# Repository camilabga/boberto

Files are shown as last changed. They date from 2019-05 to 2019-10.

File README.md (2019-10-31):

# Boberto: 2019 IEEE Open Competition Robot

Boberto was a robot developed by six students of LAR-UFRN (https://github.com/lar-ect). The competition consisted in proposing, developing and manufacturing a robot able to solve a portuary challenge.

2019 IEEE Open was a part of LARC (Latin American Robotics Competition) and happened in Rio Grande, RS, Brazil. The robot described here accomplished the second place, but is also currently the two-time Brazilian champion in the category.

The main goal was deposit as much containers as possible in a enviroment with a simulation of two ships (one blue and other green) and one train (red). Each container had a different pontuation. The team with the greatest score would win the challenge.

Boberto was able to:
1. Identify and advance to a container zone;
2. Choose a container to pick and check its color;
3. If it consisted in a Blue/Green container, grab it and go to the ship zone;
4. If it consisted in a Red container, ignore it and keep moving to the next pile;
5. Come back and do it all over again;

The official document of the competition can be found [here](http://www.cbrobotica.org/wp-content/uploads/OPEN2018_2019_en.pdf).

The students that composed the team of LAR-UFRN were:
* Álvaro Portela (https://github.com/alvaropfn)
* Camila Barbosa (https://github.com/camilabga)
* Gabriel Vantuil (https://github.com/GabrielVantuil)
* Luiz Felipe Santana (https://github.com/LuizFelipeLemon)
* Richardson Santiago (https://github.com/vanluwin)
* Wendell Alves (https://github.com/wendellalves)

## Using [PlatformIO Cli](http://docs.platformio.org/en/latest/)

* Installing

```console
user@computer:~$ sudo python -c "$(curl -fsSL https://raw.githubusercontent.com/platformio/platformio/develop/scripts/get-platformio.py)"
```

* Uploading the code

```console
user@computer:~/IEEE-2019 $ pio run -t upload --upload-port=/dev/ttyUSB0
```

## Arduino Mega Schema

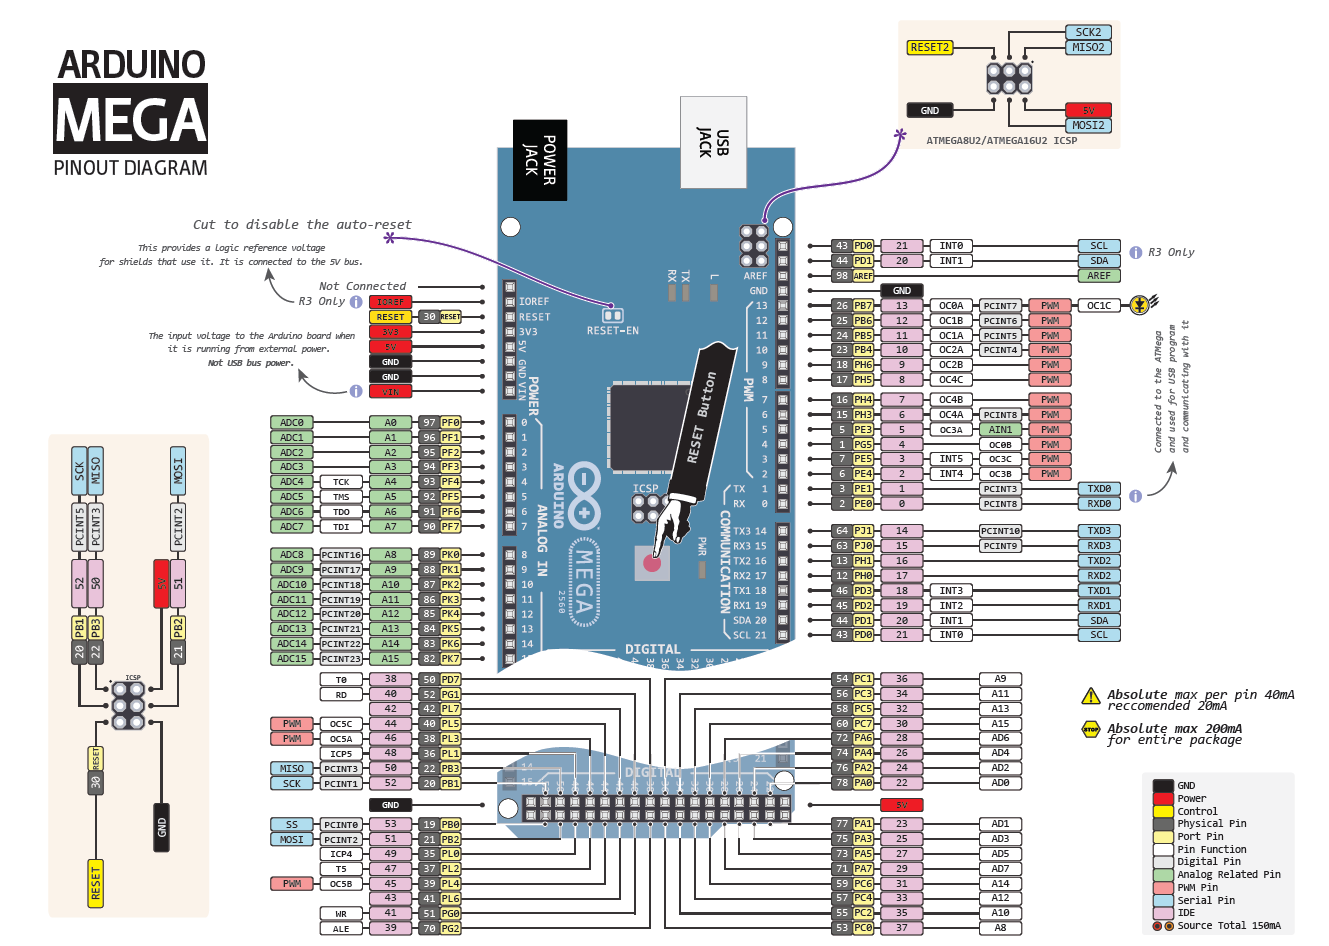
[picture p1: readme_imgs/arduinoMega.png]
arduinoMega


## Boberto Pinout

### Stepper motor

| Port | Pin |
|:---: |:---:|
| Dir | 52 |
| Step | 50 |
| Enable | 13 |

### H Bridge 1

| Port | Pin |
|:---: |:---:|
| Claw_DC 1 | 11 |
| Claw_DC 2 | 12 |
| Motor 2.1 | 9 |
| Motor 2.2 | 10 |

### H Bridge 2

| Port | Pin |
|:---: |:---:|
| Back Left 2  | 7 |
| Back Left 1  | 8 |
| Back Right 2 | 6 |
| Back Right 1 | 5 |

### H Bridge 3

| Port | Pin |
|:---:|:---:|
| Front Right 1 | 45 |
| Front Right 2 | 4 |
| Front Left 1  | 46 |
| Front Left 2  | 44 |

### Encoders

| Port | Pin |
|:---:|:---:|
| Back Left  | 3 |
| Back Right | 2 |
| Front Right| 18 |
| Front Left | 19 |

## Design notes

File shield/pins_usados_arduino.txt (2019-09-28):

Pin:

- Motor de passo
	- 52 Dir
	- 50 Step
	- 13 enable

- Ponte H 1
	- 11 input 1
	- 12 input 2
	- 9 input 3
	- 10 input 4

- Ponte H 2
	- 7 input 1
	- 8 input 2
	- 6 input 3
	- 5 input 4

- Ponte H 3
	- 45 input 1
	- 4 input 2
	- 46 input 3
	- 44 input 4

- Encoders (Interrupt)
	- 3 - motor 1
	- 2 - motor 2
	- 18 - motor 3
	- 19 - motor 4

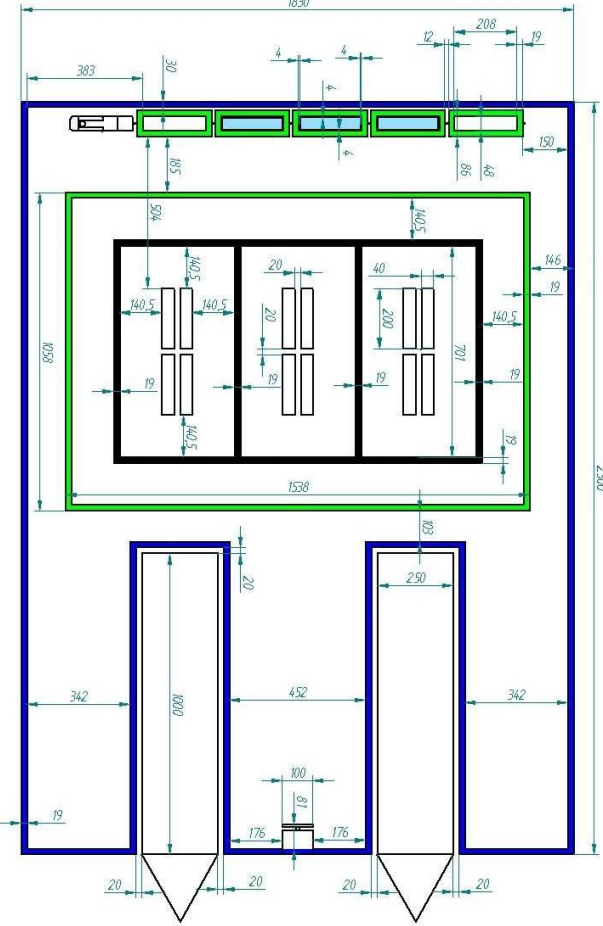
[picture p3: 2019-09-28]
readme_imgs/zones.png

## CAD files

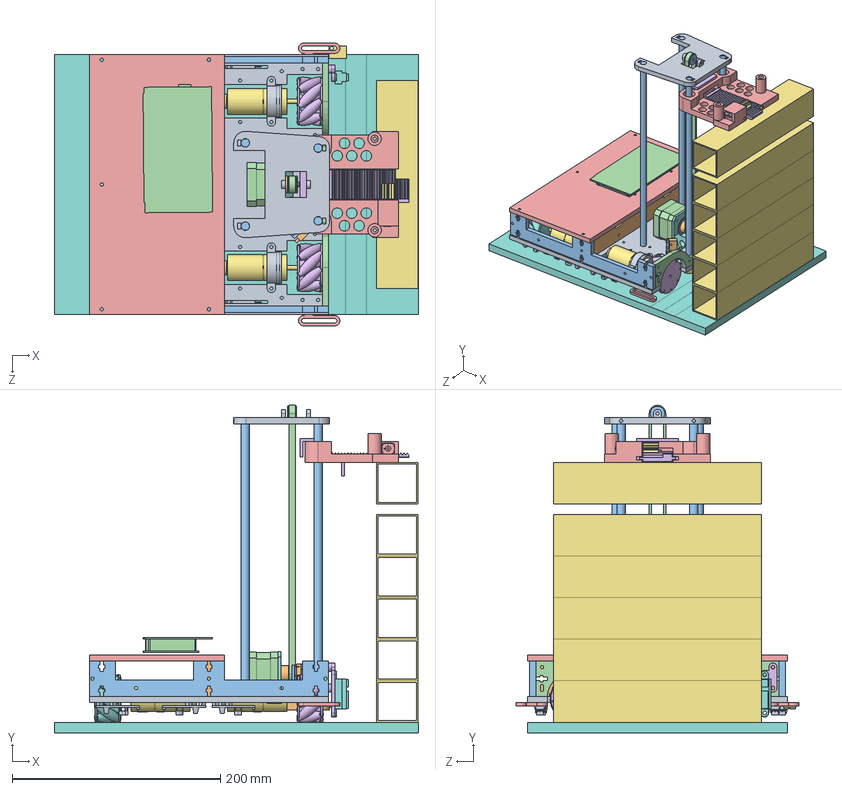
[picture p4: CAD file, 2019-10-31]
CAD/#Robo completo.SLDASM
350.0 x 315.0 x 272.0 mm
base
chassis meio
chassis reforco x 2
chassis direita x 2
segundo andar
Mecanum x 2
motor 12v com reducao e encoder x 4
EspelharMecanum x 2
suporte motor x 2
suporte barras base x 2
barra lisa 8mm x 4
nema17 (30mm altura)
suporte garra
cremalheira
engrenagem servo maior
suporte nema
suporte barras topo
polia gt2
polia com rolamento
correia
motor N20
suporte correia v2
container x 6
chao
sensor de linha x 6
endstop
suporte fim de curso
Ramps + arduino
suporte sensor de azul x 2
suporte sharp
sensor de azul
sharp

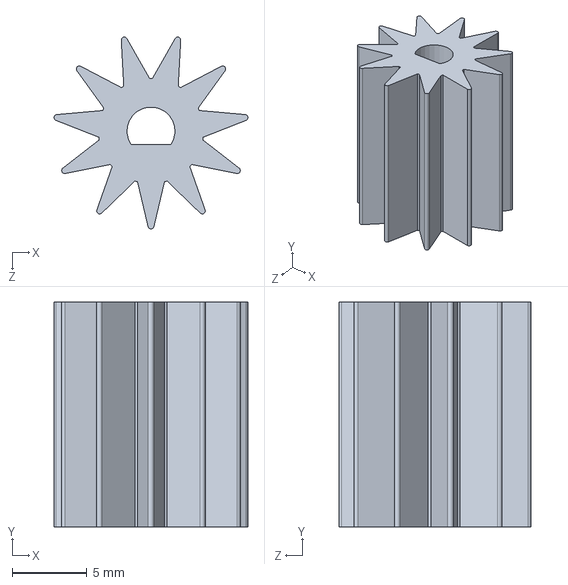
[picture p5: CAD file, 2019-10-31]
CAD/engrenagem servo maior.SLDPRT
12.9 x 15.0 x 12.8 mm

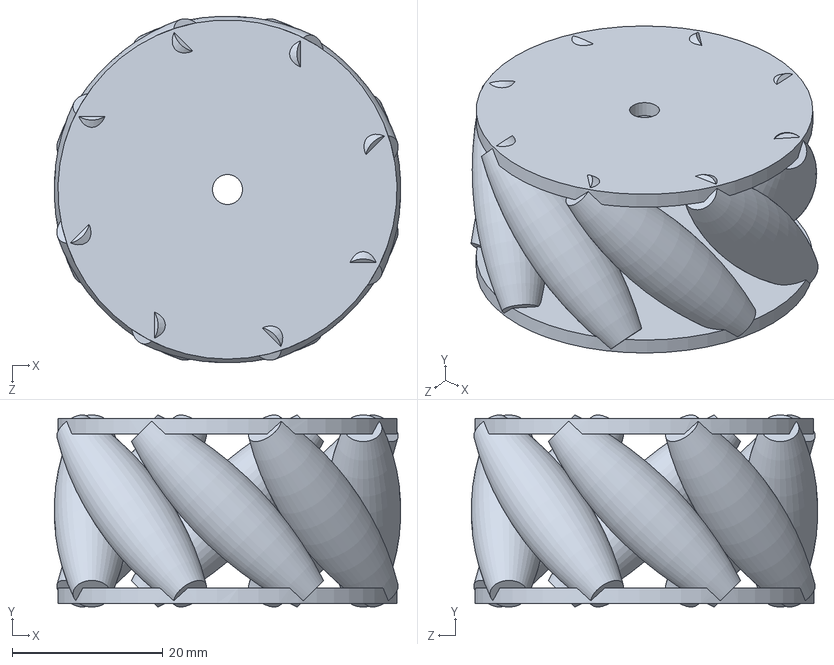
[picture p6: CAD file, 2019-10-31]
CAD/Mecanum.SLDPRT
45.9 x 25.5 x 45.9 mm

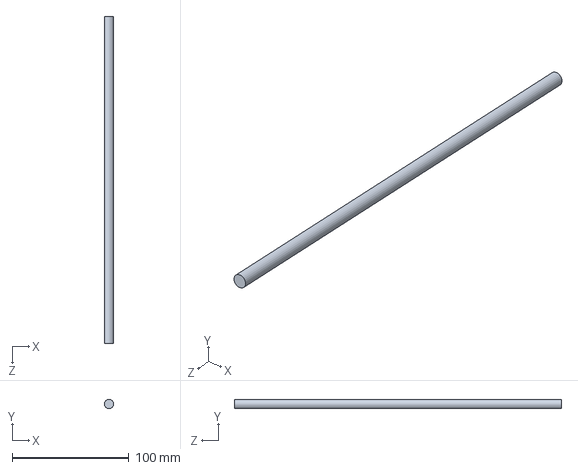
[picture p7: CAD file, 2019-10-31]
CAD/barra lisa 8mm.SLDPRT
8.00 x 8.00 x 280.0 mm

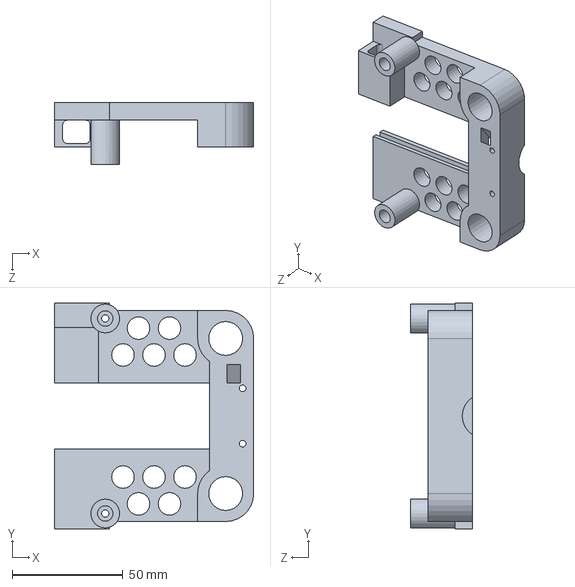
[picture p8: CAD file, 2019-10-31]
CAD/suporte garra.SLDPRT
90.0 x 102.0 x 28.0 mm

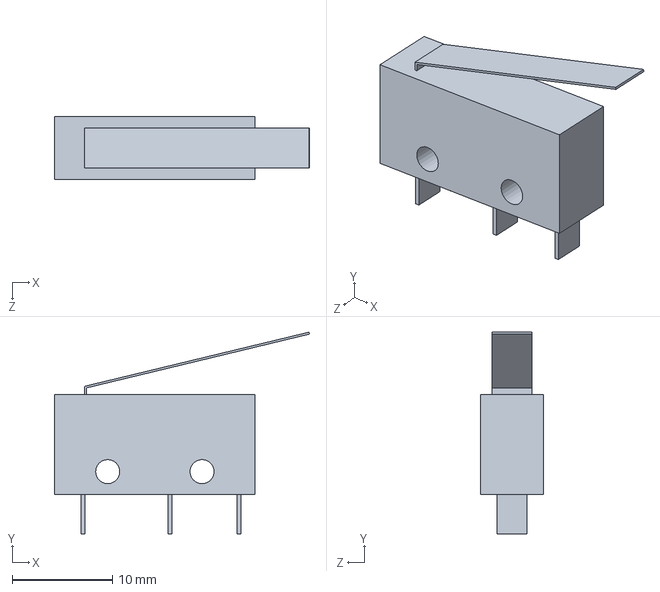
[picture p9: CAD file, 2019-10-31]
CAD/endstop.SLDPRT
25.4 x 20.1 x 6.30 mm

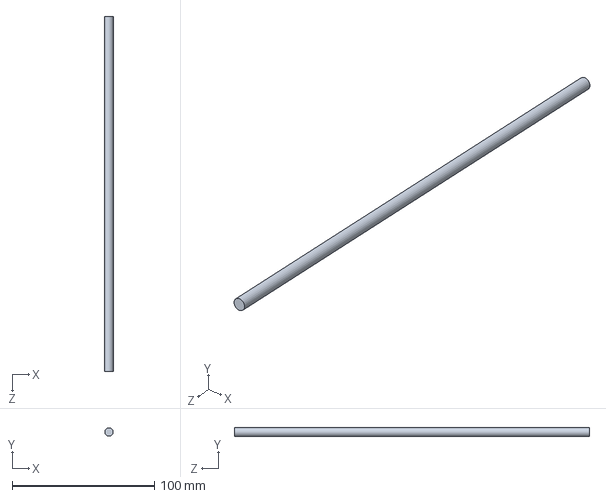
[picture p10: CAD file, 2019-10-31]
CAD/barra lisa 6mm.SLDPRT
6.00 x 6.00 x 250.0 mm

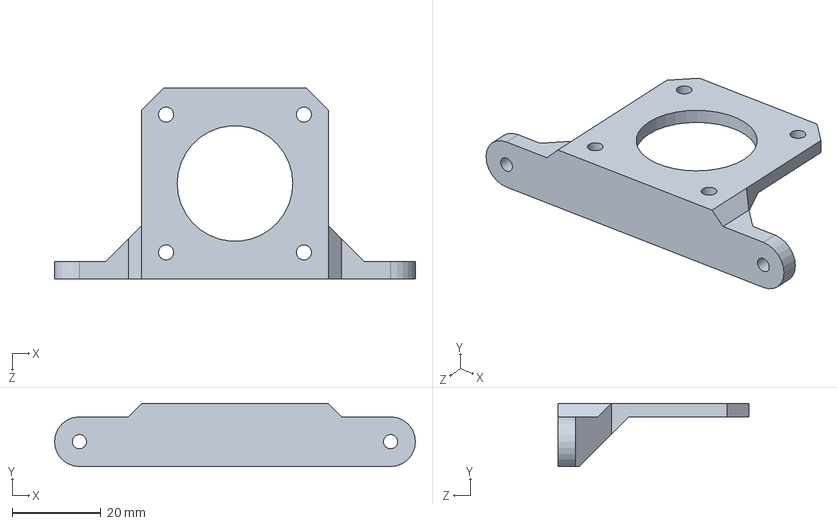
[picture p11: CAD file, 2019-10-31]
CAD/suporte nema.SLDPRT
81.2 x 14.2 x 43.0 mm

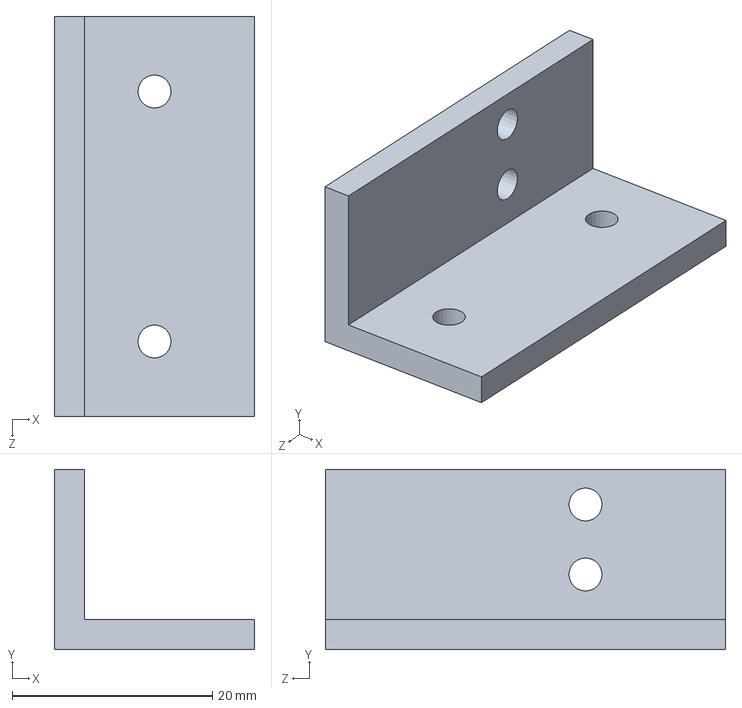
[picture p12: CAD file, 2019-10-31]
CAD/suporte correia v2.SLDPRT
20.0 x 18.0 x 40.0 mm

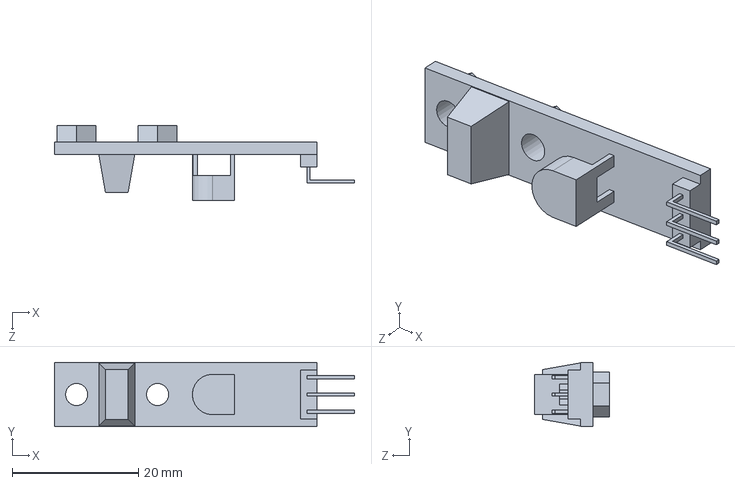
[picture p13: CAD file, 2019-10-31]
CAD/sensor de linha.SLDPRT
47.4 x 10.2 x 11.9 mm

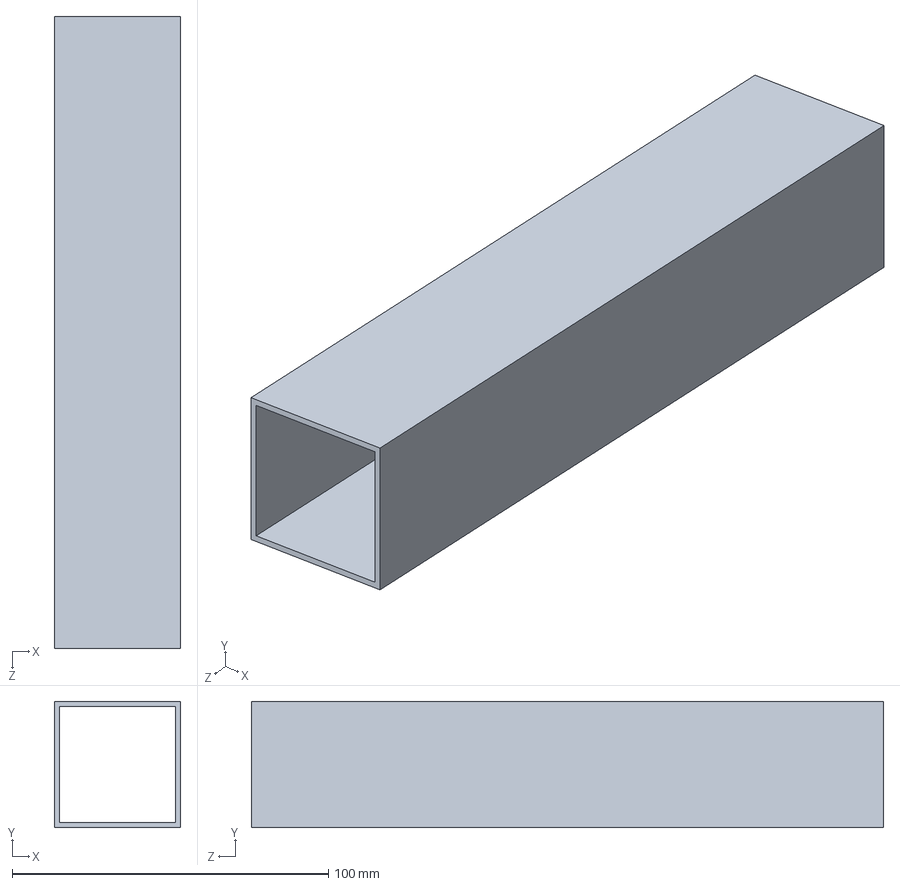
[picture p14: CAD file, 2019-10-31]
CAD/container.SLDPRT
40.0 x 40.0 x 200.0 mm

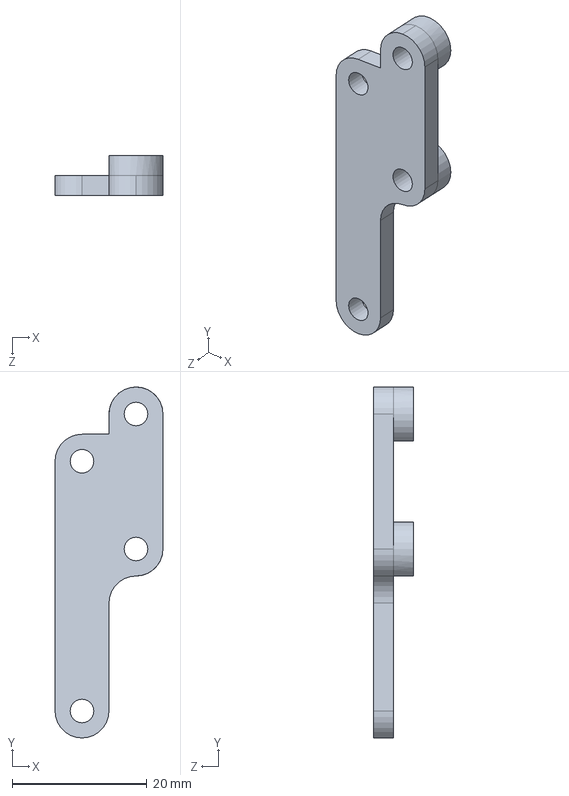
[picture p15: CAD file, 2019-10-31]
CAD/suporte sharp.SLDPRT
16.0 x 52.0 x 6.00 mm

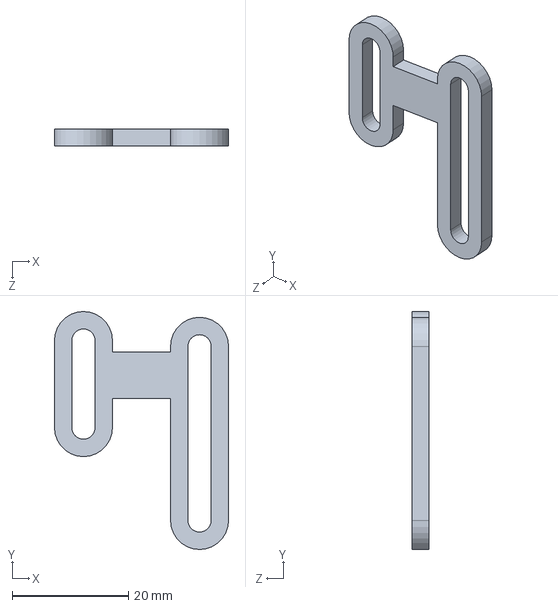
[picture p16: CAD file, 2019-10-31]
CAD/suporte sensor de azul.SLDPRT
30.0 x 41.0 x 3.00 mm

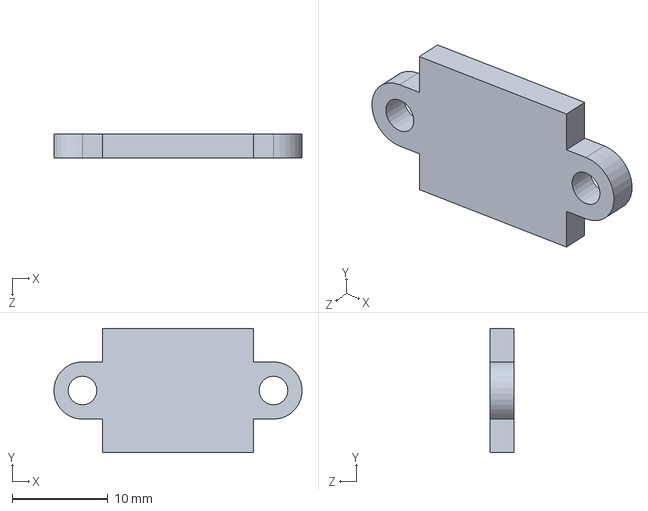
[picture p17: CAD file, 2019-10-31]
CAD/vl53l0x.SLDPRT
26.0 x 13.0 x 2.50 mm

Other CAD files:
CAD/2d (laser)/todas as peças.DWG
CAD/EspelharMecanum.SLDPRT
CAD/sharp.SLDPRT
CAD/suporte barras base.SLDPRT
CAD/2d (laser)/base.SLDDRW
CAD/2d (laser)/chassis 2x reforco + meio.SLDDRW
CAD/2d (laser)/chassis direita.SLDDRW
CAD/2d (laser)/todas as peças.SLDDRW
CAD/PCB + arduino.SLDPRT
CAD/Printable parts/cremalheira.STL
CAD/Printable parts/engrenagem servo maior.STL
CAD/Printable parts/suporte barras base.STL
CAD/Printable parts/suporte barras topo.STL
CAD/Printable parts/suporte correia v2.STL
CAD/Printable parts/suporte fim de curso.STL
CAD/Printable parts/suporte garra.STL
CAD/Printable parts/suporte motor.STL
CAD/Printable parts/suporte nema.STL
CAD/Printable parts/suporte sensor de azul.STL
CAD/Servo 9g.SLDPRT
CAD/apoio container.SLDPRT
CAD/base.SLDPRT
CAD/chao.SLDPRT
CAD/chassis direita.SLDPRT
CAD/chassis meio.SLDPRT
CAD/chassis reforco.SLDPRT
CAD/chassis.SLDPRT
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

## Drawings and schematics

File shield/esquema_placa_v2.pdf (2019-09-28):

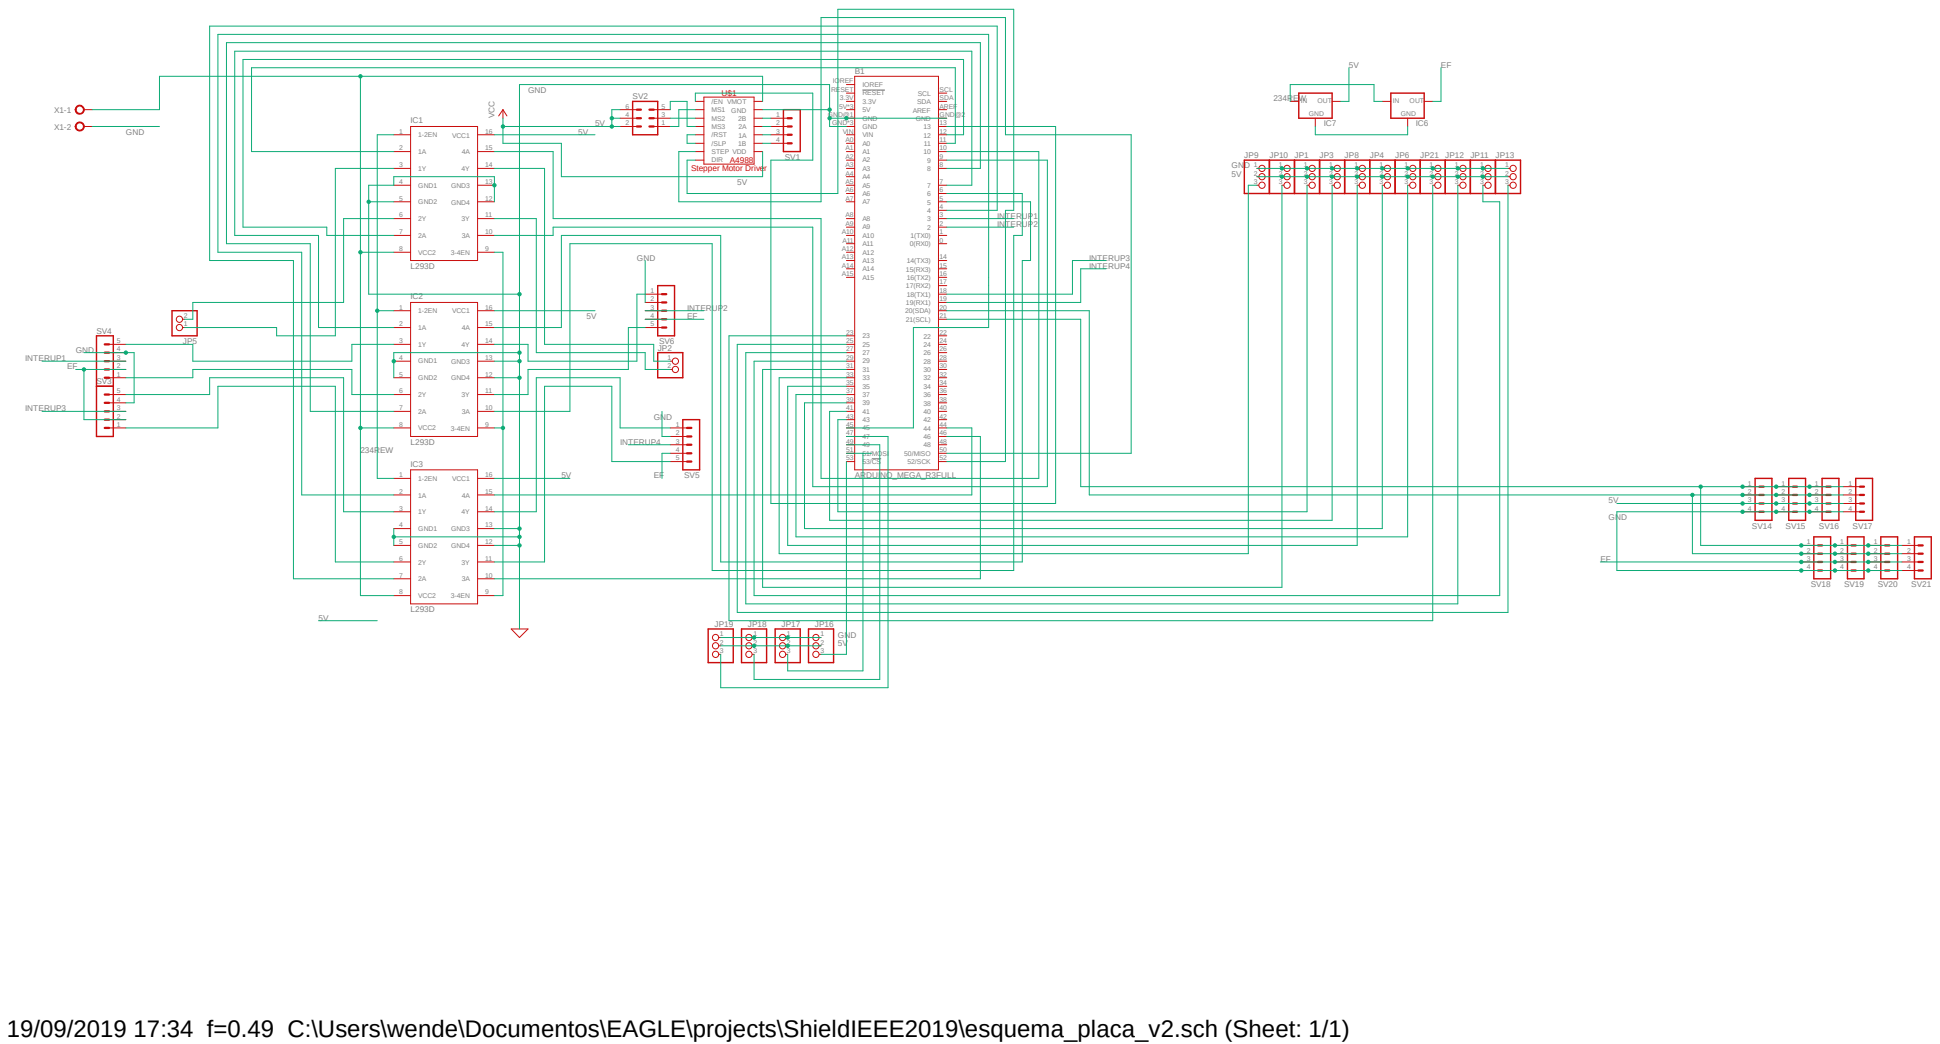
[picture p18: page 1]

GND1 4 GND4 3Y 3A | | | | 5V

GND2 5 | 12

2A 7 VCC2 8 | 10

19/09/2019 17:34 f=0.49 C:\Users\wende\Documentos\EAGLE\projects\ShieldIEEE2019\esquema_placa_v2.sch (Sheet: 1/1)

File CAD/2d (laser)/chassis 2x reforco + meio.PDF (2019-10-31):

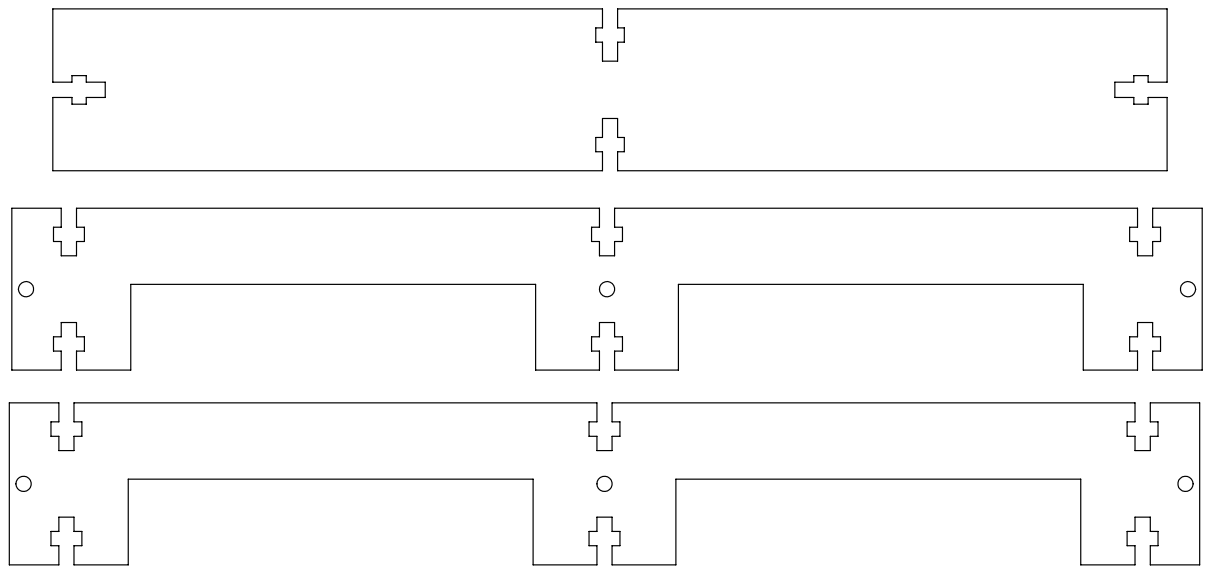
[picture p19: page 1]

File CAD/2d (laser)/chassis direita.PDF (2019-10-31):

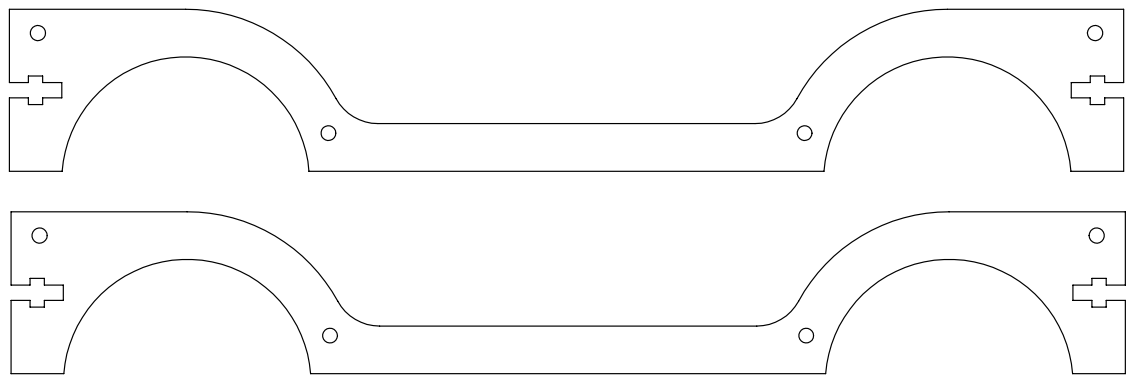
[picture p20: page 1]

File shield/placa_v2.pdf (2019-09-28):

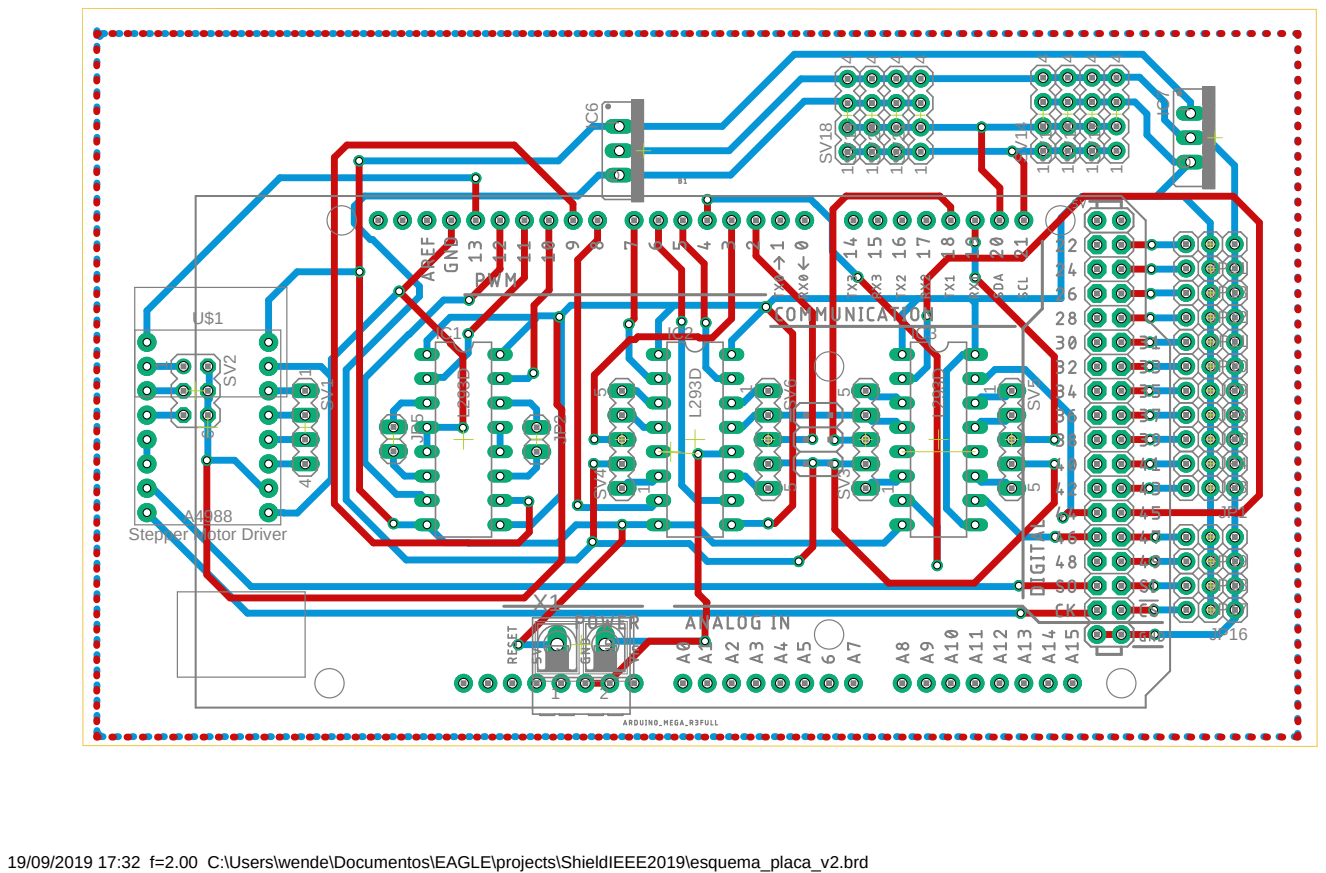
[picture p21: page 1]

19/09/2019 17:32 f=2.00 C:\Users\wende\Documentos\EAGLE\projects\ShieldIEEE2019\esquema_placa_v2.brd

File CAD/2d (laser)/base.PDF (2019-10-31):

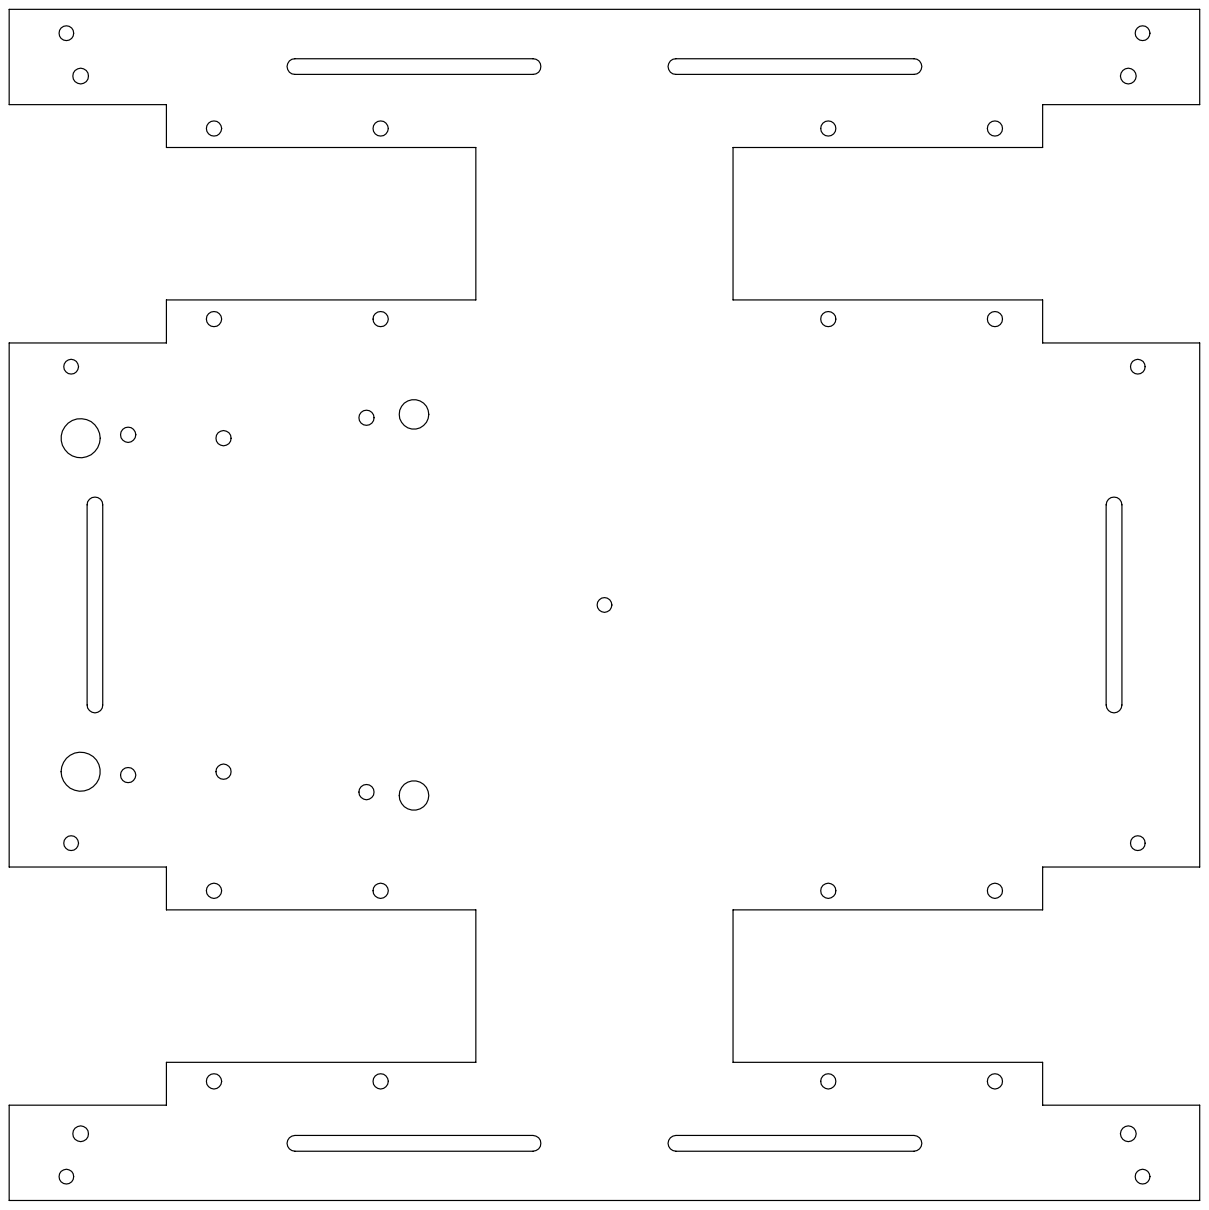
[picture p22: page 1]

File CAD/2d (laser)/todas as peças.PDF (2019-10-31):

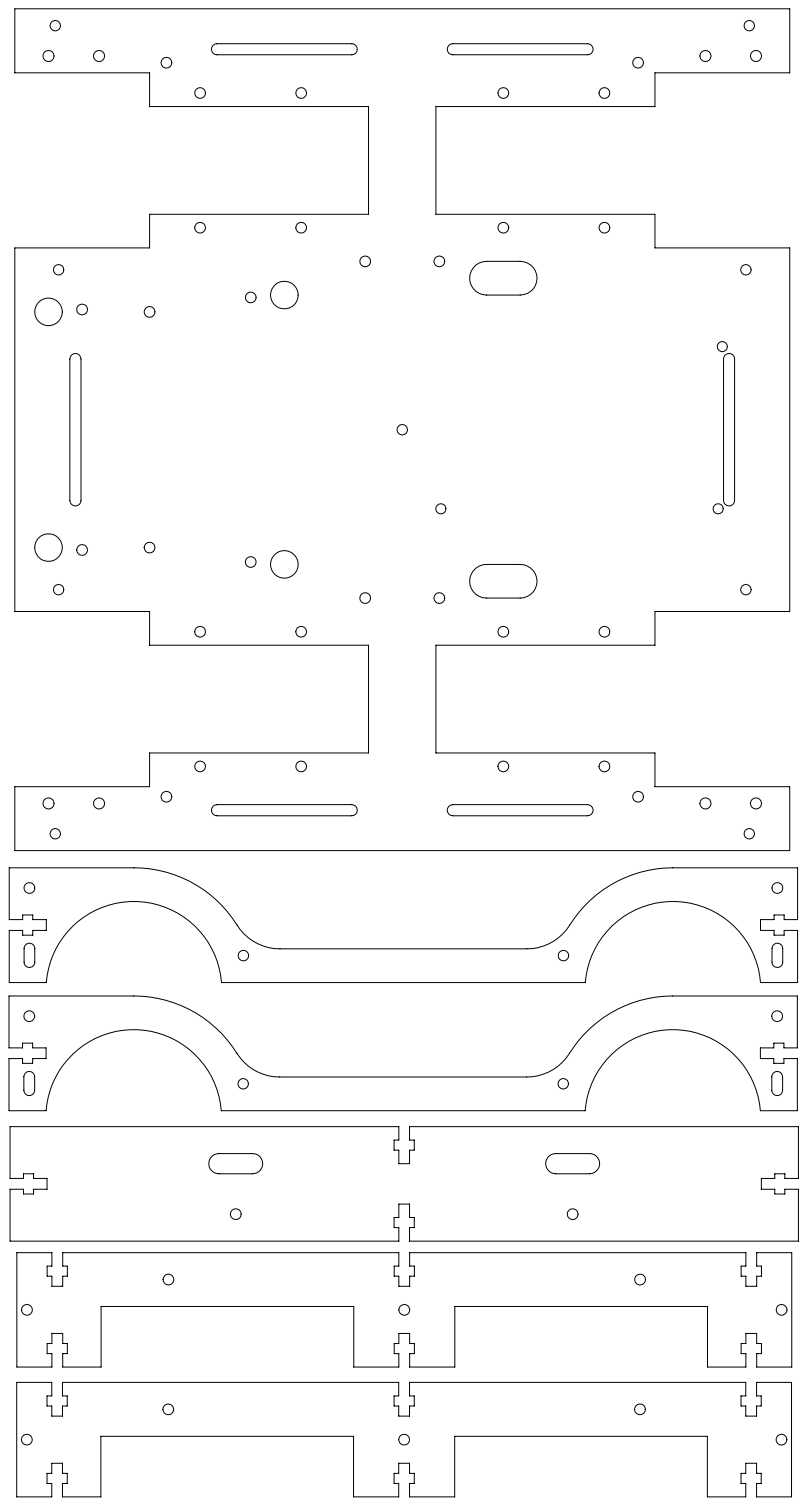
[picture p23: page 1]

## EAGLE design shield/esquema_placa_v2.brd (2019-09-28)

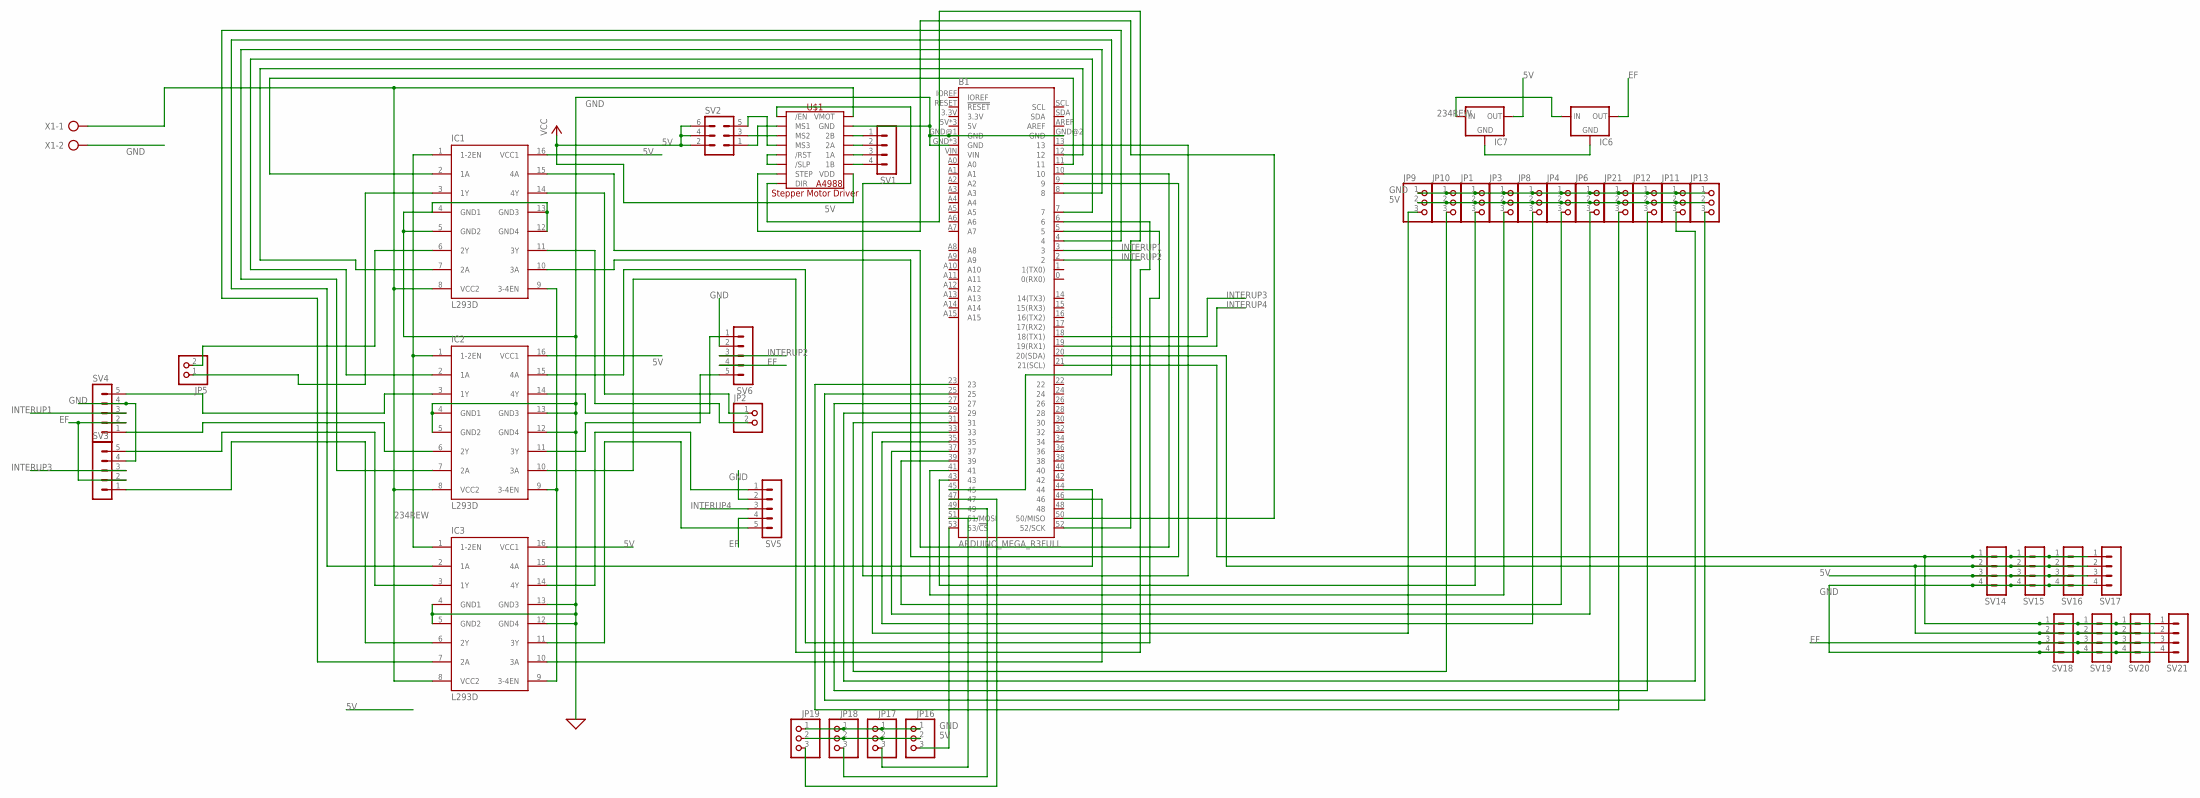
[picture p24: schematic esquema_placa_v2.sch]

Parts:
B1: ARDUINO_MEGA_R3FULL; ARDUINO_MEGA_NO_SILK
IC1, IC2, IC3: L293D; DIL16
IC6, IC7: 78XXS
JP1, JP3, JP4, JP6, JP8, JP9, JP10, JP11, JP12, JP13, JP16, JP17, JP18, JP19, JP21: PINHD-1X3; 1X03
JP2, JP5: PINHD-1X2; 1X02
SV1, SV14, SV15, SV16, SV17, SV18, SV19, SV20, SV21: MA04-1
SV2: MA03-2
SV3, SV4, SV5, SV6: MA05-1
U$1: A4988_STEP
X1: AK500/2-H

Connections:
5V: IC1.1 (1-2EN), IC1.9 (3-4EN), IC1.16 (VCC1), IC2.1 (1-2EN), IC2.9 (3-4EN), IC2.16 (VCC1), IC3.1 (1-2EN), IC3.9 (3-4EN), IC3.16 (VCC1), IC7.OUT, JP1.2, JP3.2, JP4.2, JP6.2, JP8.2, JP9.2, JP10.2, JP11.2, JP12.2, JP13.2, JP16.2, JP17.2, JP18.2, JP19.2, JP21.2, SV2.2, SV2.4, SV2.6, SV14.3, SV15.3, SV16.3, SV17.3, U$1.VDD
234REW: IC1.8 (VCC2), IC2.8 (VCC2), IC3.8 (VCC2), IC6.IN, IC7.IN, U$1.VMOT, X1.1
EF: IC6.OUT, SV3.2, SV4.2, SV5.4, SV6.4, SV18.3, SV19.3, SV20.3, SV21.3
GND: B1.GND, B1.GND@1 (GND), B1.GND@2 (GND), B1.GND@3 (GND), B1.GND@4 (GND), IC1.4 (GND1), IC1.5 (GND2), IC1.12 (GND4), IC1.13 (GND3), IC2.4 (GND1), IC2.5 (GND2), IC2.12 (GND4), IC2.13 (GND3), IC3.4 (GND1), IC3.5 (GND2), IC3.12 (GND4), IC3.13 (GND3), IC6.GND, IC7.GND, JP1.1, JP3.1, JP4.1, JP6.1, JP8.1, JP9.1, JP10.1, JP11.1, JP12.1, JP13.1, JP16.1, JP17.1, JP18.1, JP19.1, JP21.1, SV3.4, SV4.4, SV5.2, SV6.2, SV14.4, SV15.4, SV16.4, SV17.4, SV18.4, SV19.4, SV20.4, SV21.4, U$1.GND, U$1.GND2 (GND), X1.2
INTERUP1: B1.3, SV4.3
INTERUP2: B1.2, SV6.3
INTERUP3: B1.18 (18(TX1)), SV3.3
INTERUP4: B1.19 (19(RX1)), SV5.3
unnamed: B1.53 (53/!CS), JP16.3
unnamed: IC1.3 (1Y), JP5.1
unnamed: IC1.6 (2Y), JP5.2
unnamed: IC2.3 (1Y), SV4.5
unnamed: B1.45, IC3.2 (1A)
unnamed: IC2.6 (2Y), SV4.1
unnamed: IC3.3 (1Y), SV3.5
unnamed: IC3.6 (2Y), SV3.1
unnamed: IC2.14 (4Y), SV6.1
unnamed: IC2.11 (3Y), SV6.5
unnamed: IC3.14 (4Y), SV5.1
unnamed: IC3.11 (3Y), SV5.5
unnamed: IC1.11 (3Y), JP2.2
unnamed: IC1.14 (4Y), JP2.1
unnamed: B1.12, IC1.7 (2A)
unnamed: B1.11, IC1.2 (1A)
unnamed: B1.7, IC2.2 (1A)
unnamed: B1.8, IC2.7 (2A)
unnamed: B1.43, JP1.3
unnamed: B1.4, IC3.7 (2A)
unnamed: B1.10, IC1.15 (4A)
unnamed: B1.9, IC1.10 (3A)
unnamed: B1.5, IC2.15 (4A)
unnamed: B1.6, IC2.10 (3A)
unnamed: U$1./RST, U$1./SLP
unnamed: B1.46, IC3.10 (3A)
unnamed: B1.41, JP3.3
unnamed: SV1.1, U$1.2B
unnamed: SV1.2, U$1.2A
unnamed: SV1.3, U$1.1A
unnamed: SV1.4, U$1.1B
unnamed: SV2.3, U$1.MS2
unnamed: SV2.1, U$1.MS1
unnamed: SV2.5, U$1.MS3
unnamed: B1.44, IC3.15 (4A)
unnamed: B1.13, U$1./EN
unnamed: B1.50 (50/MISO), U$1.STEP
unnamed: B1.52 (52/SCK), U$1.DIR
unnamed: B1.39, JP4.3
unnamed: B1.51 (51/MOSI), JP17.3
unnamed: B1.49, JP18.3
unnamed: B1.47, JP19.3
unnamed: B1.37, JP6.3
unnamed: B1.35, JP8.3
unnamed: B1.33, JP9.3
unnamed: B1.31, JP10.3
unnamed: B1.29, JP11.3
unnamed: B1.27, JP12.3
unnamed: B1.25, JP13.3
unnamed: B1.20 (20(SDA)), SV14.2, SV15.2, SV16.2, SV17.2, SV18.2, SV19.2, SV20.2, SV21.2
unnamed: B1.23, JP21.3
unnamed: B1.21 (21(SCL)), SV14.1, SV15.1, SV16.1, SV17.1, SV18.1, SV19.1, SV20.1, SV21.1

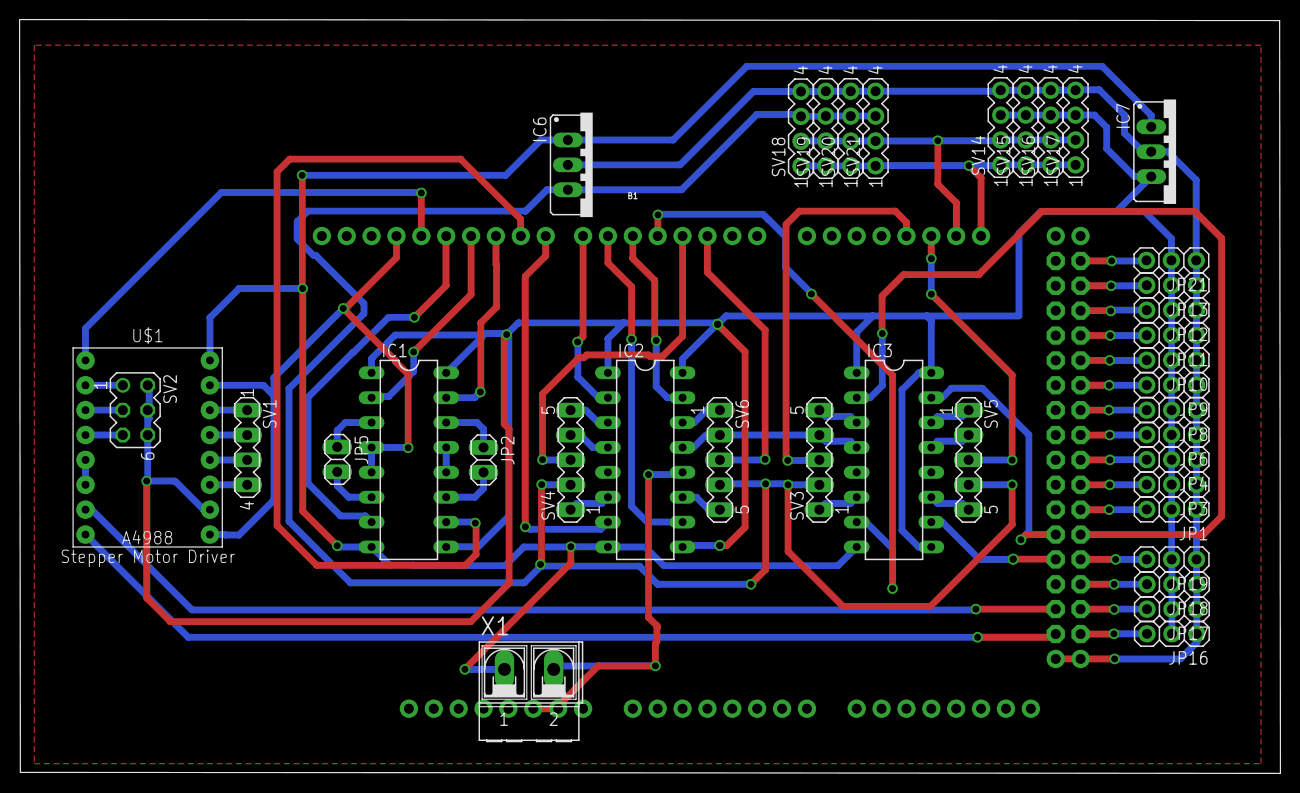
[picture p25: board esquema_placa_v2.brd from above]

Board: 2 copper layers, 128.7 x 77.0 mm, 39 parts (0 on the bottom side), 60 nets.

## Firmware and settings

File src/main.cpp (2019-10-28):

#include "Robot.hpp"

Robot boberto;

void setup() {

    Serial.begin(115200);

    boberto.begin();

    Serial.println(":: Oi, eu sou o Boberto ::");

    boberto.goToContainerZone();
    boberto.checkColor();
    boberto.catchContainer();
    boberto.goToCurrentDestination();
    while (true) {
        boberto.thereAndBackAgain();
        boberto.followLineUntilContainer(); 
        boberto.checkColor();
        boberto.catchContainer();
        boberto.goToCurrentDestination();
    
    }
}

void loop() {}

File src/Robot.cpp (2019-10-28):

#include "Robot.hpp"

Robot::Robot() {
    // Inicia os pinos dos motores
    frontRight.setPins(19, 44, 46);
    frontLeft.setPins(18, 4, 45);
    backRight.setPins(3, 7, 8);
    backLeft.setPins(2, 6, 5);

    frontLeft.begin();
    frontRight.begin();
    backLeft.begin();
    backRight.begin();

    sensorFL.setPin(23);
    sensorFR.setPin(29);
    sensorBL.setPin(27);
    sensorBR.setPin(25);

    // sensorSB.setPin(35);
    // sensorSF.setPin(34);

    // sensorFLL.setPin(31);
    sensorFRR.setPin(31);
    sensorBLL.setPin(41);

    blueSensorF.setPin(51);
    blueSensorB.setPin(49);

    // containerSensorF.setPin(41);
    containerSensorB.setPin(47);

}

Robot::~Robot() {}

void Robot::begin() {
    // Calibra o sensor de cor
    // colorSensor.ledOn();
    // Serial.println("Going to init");
    // colorSensor.init();
    // Serial.println("Initialized");
    // Serial.println("Going to calibrate");
    // colorSensor.calibrate();
    // Serial.println("Calibrated");

    // Seta a posição inicial da garra
    // claw.goHome();
    // claw.goToContainer(1.05);

    // Serial.println("Calibrating...");
    // delay(500);
    // colorSensor.calibrate();
    // Serial.println("Calibrated");
    // delay(500);

    // claw.retract();
    claw.goHome();
    claw.goToContainer(6.1);
}

void Robot::stop() {
    frontLeft.stop();
    frontRight.stop();
    backLeft.stop();
    backRight.stop();
}

void Robot::forward(uint8_t goal, int16_t vel) {
    if (!goal) {
        frontLeft.forward(0, vel);
        frontRight.forward(0, vel);
        backLeft.forward(0, vel);
        backRight.forward(0, vel);
    } else {
        for (byte i = 0; i < goal; i++) {
            frontLeft.forward(100, vel);
            frontRight.forward(100, vel);
            backLeft.forward(100, vel);
            backRight.forward(100, vel);

            while (frontLeft.getFinished() or frontRight.getFinished() or
                   backLeft.getFinished() or backRight.getFinished()) {
                delay(1);
            }
        }
        stop();
    }
}

void Robot::backward(uint8_t goal, int16_t vel) {
    if (!goal) {
        frontLeft.backward(0, vel);
        frontRight.backward(0, vel);
        backLeft.backward(0, vel);
        backRight.backward(0, vel);
    } else {
        for (byte i = 0; i < goal; i++) {
            frontLeft.backward(100, vel);
            frontRight.backward(100, vel);
            backLeft.backward(100, vel);
            backRight.backward(100, vel);

            while (frontLeft.getFinished() or frontRight.getFinished() or
                   backLeft.getFinished() or backRight.getFinished()) {
                delay(1);
            }
        }
        stop();
    }
}

void Robot::sidewaysRight(uint8_t goal, int16_t vel) {
    if (!goal) {
        frontLeft.forward(0, vel);
        frontRight.backward(0, vel);
        backLeft.backward(0, vel);
        backRight.forward(0, vel);
    } else {
        for (byte i = 0; i < goal; i++) {
            frontLeft.forward(100, vel);
            frontRight.backward(100, vel);
            backLeft.backward(100, vel);
            backRight.forward(100, vel);

            while (frontLeft.getFinished() or frontRight.getFinished() or
                   backLeft.getFinished() or backRight.getFinished()) {
                delay(1);
            }
        }
        stop();
    }
}

void Robot::sidewaysLeft(uint8_t goal, int16_t vel) {
    if (!goal) {
        frontLeft.backward(0, vel);
        frontRight.forward(0, vel);
        backLeft.forward(0, vel);
        backRight.backward(0, vel);
    } else {
        for (byte i = 0; i < goal; i++) {
            frontLeft.backward(100, vel);
            frontRight.forward(100, vel);
            backLeft.forward(100, vel);
            backRight.backward(100, vel);

            while (frontLeft.getFinished() or frontRight.getFinished() or
                   backLeft.getFinished() or backRight.getFinished()) {
                delay(1);
            }
        }
        stop();
    }
}

void Robot::rotateLeft(uint8_t goal, int16_t vel) {
    if (!goal) {
        frontLeft.backward(0, vel);
        frontRight.forward(0, vel);
        backLeft.backward(0, vel);
        backRight.forward(0, vel);
    } else {
        for (byte i = 0; i < goal; i++) {
            frontLeft.backward(100, vel);
            frontRight.forward(100, vel);
            backLeft.backward(100, vel);
            backRight.forward(100, vel);

            while (frontLeft.getFinished() or frontRight.getFinished() or
                   backLeft.getFinished() or backRight.getFinished()) {
                delay(1);
            }
        }
        stop();
    }
}

void Robot::rotateRight(uint8_t goal, int16_t vel) {
    if (!goal) {
        frontLeft.forward(0, vel);
        frontRight.backward(0, vel);
        backLeft.forward(0, vel);
        backRight.backward(0, vel);
    } else {
        for (byte i = 0; i < goal; i++) {
            frontLeft.forward(100, vel);
            frontRight.backward(100, vel);
            backLeft.forward(100, vel);
            backRight.backward(100, vel);

            while (frontLeft.getFinished() or frontRight.getFinished() or
                   backLeft.getFinished() or backRight.getFinished()) {
                delay(1);
            }
        }
        stop();
    }
}

void Robot::moveRightForward(uint8_t goal, int16_t vel) {
    if (!goal) {
        frontLeft.forward(0, vel);
        frontRight.stop();
        backLeft.stop();
        backRight.forward(0, vel);
    } else {
        for (byte i = 0; i < goal; i++) {
            frontLeft.forward(100, vel);
            frontRight.stop();
            backLeft.stop();
            backRight.forward(100, vel);

            while (frontLeft.getFinished() or frontRight.getFinished() or
                   backLeft.getFinished() or backRight.getFinished()) {
                delay(1);
            }
        }
        stop();
    }
}

void Robot::moveRightBackward(uint8_t goal, int16_t vel) {
    if (!goal) {
        frontLeft.stop();
        frontRight.backward(0, vel);
        backLeft.backward(0, vel);
        backRight.stop();
    } else {
        for (byte i = 0; i < goal; i++) {
            frontLeft.stop();
            frontRight.backward(100, vel);
            backLeft.backward(100, vel);
            backRight.stop();

            while (frontLeft.getFinished() or frontRight.getFinished() or
                   backLeft.getFinished() or backRight.getFinished()) {
                delay(1);
            }
        }
        stop();
    }
}
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

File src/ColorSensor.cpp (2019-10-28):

#include "ColorSensor.hpp"

ColorSensor::ColorSensor(uint8_t _ledPin) : ledPin(_ledPin) {}

void ColorSensor::init() {
    pinMode(ledPin, OUTPUT);

    colorCap[0] = 9;
    colorCap[1] = 9;
    colorCap[2] = 2;
    colorCap[3] = 5;

    colorInt[0] = 2048;
    colorInt[1] = 2048;
    colorInt[2] = 2048;
    colorInt[3] = 2048;

    /*
        Sensor gain registers, CAP_... to select number of capacitors.
        value must be <= 15
    */
    writeRegister(colorCap[RED] & 0xF, CAP_RED);
    writeRegister(colorCap[GREEN] & 0xF, CAP_GREEN);
    writeRegister(colorCap[BLUE] & 0xF, CAP_BLUE);
    writeRegister(colorCap[CLEAR] & 0xF, CAP_CLEAR);

    /*
        Write sensor gain registers INT_...
        to select integration time value must be <= 4096
    */
    writeRegister((unsigned char)colorInt[RED], INT_RED_LO);
    writeRegister((unsigned char)((colorInt[RED] & 0x1FFF) >> 8), INT_RED_HI);
    writeRegister((unsigned char)colorInt[BLUE], INT_BLUE_LO);
    writeRegister((unsigned char)((colorInt[BLUE] & 0x1FFF) >> 8), INT_BLUE_HI);
    writeRegister((unsigned char)colorInt[GREEN], INT_GREEN_LO);
    writeRegister((unsigned char)((colorInt[GREEN] & 0x1FFF) >> 8),
                  INT_GREEN_HI);
    writeRegister((unsigned char)colorInt[CLEAR], INT_CLEAR_LO);
    writeRegister((unsigned char)((colorInt[CLEAR] & 0x1FFF) >> 8),
                  INT_CLEAR_HI);
}

void ColorSensor::calibrate() {
    delay(2);
    calibrateColor();
    calibrateClear();
    calibrateCapacitors();
}

void ColorSensor::ledOn() { digitalWrite(ledPin, HIGH); }

void ColorSensor::ledOff() { digitalWrite(ledPin, LOW); }

int ColorSensor::calibrateClear() {
    int gainFound = 0;
    int upperBox = 4096;
    int lowerBox = 0;
    int half;

    while (!gainFound) {
        half = ((upperBox - lowerBox) / 2) + lowerBox;

        if (half == lowerBox)
            gainFound = 1;
        else {
            writeInt(INT_CLEAR_LO, half);
            performMeasurement();
            int halfValue = readRegisterInt(DATA_CLEAR_LO);

            if (halfValue > 1000)
                upperBox = half;
            else if (halfValue < 1000)
                lowerBox = half;
            else
                gainFound = 1;
        }
    }

    return half;
}

int ColorSensor::calibrateColor() {
    int gainFound = 0;
    int upperBox = 4096;
    int lowerBox = 0;
    int half;

    while (!gainFound) {
        half = ((upperBox - lowerBox) / 2) + lowerBox;

        if (half == lowerBox)
            gainFound = 1;
        else {
            writeInt(INT_RED_LO, half);
            writeInt(INT_GREEN_LO, half);
            writeInt(INT_BLUE_LO, half);

            performMeasurement();
            int halfValue = 0;

            halfValue = max(halfValue, readRegisterInt(DATA_RED_LO));
            halfValue = max(halfValue, readRegisterInt(DATA_GREEN_LO));
            halfValue = max(halfValue, readRegisterInt(DATA_BLUE_LO));

            if (halfValue > 1000)
                upperBox = half;
            else if (halfValue < 1000)
                lowerBox = half;
            else
                gainFound = 1;
        }
    }

    return half;
}

void ColorSensor::calibrateCapacitors() {
    int calibrationRed = 0;
    int calibrationBlue = 0;
    int calibrationGreen = 0;
    int calibrated = 0;

    int oldDiff = 5000;

    while (!calibrated) {
        /*
            sensor gain setting (Avago app note 5330)
            CAPs are 4bit (higher value will result in lower output)
        */
        writeRegister(calibrationRed, CAP_RED);
        writeRegister(calibrationGreen, CAP_GREEN);
        writeRegister(calibrationBlue, CAP_BLUE);

        // int colorGain = _calibrateColorGain();
        int colorGain = readRegisterInt(INT_RED_LO);
        writeInt(INT_RED_LO, colorGain);
        writeInt(INT_GREEN_LO, colorGain);
        writeInt(INT_BLUE_LO, colorGain);

        int maxRead = 0;
        int minRead = 4096;
        int red = 0;
        int green = 0;
        int blue = 0;

        for (int i = 0; i < 4; i++) {
            performMeasurement();
            red += readRegisterInt(DATA_RED_LO);
            green += readRegisterInt(DATA_GREEN_LO);
            blue += readRegisterInt(DATA_BLUE_LO);
        }

        red /= 4;
        green /= 4;
        blue /= 4;

        maxRead = max(maxRead, red);
        maxRead = max(maxRead, green);
        maxRead = max(maxRead, blue);

        minRead = min(minRead, red);
        minRead = min(minRead, green);
        minRead = min(minRead, blue);

        int diff = maxRead - minRead;

        if (oldDiff != diff) {
            if ((maxRead == red) && (calibrationRed < 15))
                calibrationRed++;
            else if ((maxRead == green) && (calibrationGreen < 15))
                calibrationGreen++;
            else if ((maxRead == blue) && (calibrationBlue < 15))
                calibrationBlue++;
        } else
            calibrated = 1;

        oldDiff = diff;

        int rCal = calibrationRed;
        int gCal = calibrationGreen;
        int bCal = calibrationBlue;
    }
}

void ColorSensor::writeInt(int address, int gain) {
    if (gain < 4096) {
        byte msb = gain >> 8;
        byte lsb = gain;

        writeRegister(lsb, address);
        writeRegister(msb, address + 1);
    }
}

void ColorSensor::performMeasurement() {
    writeRegister(0x01, 0x00);  // start sensing
    while (readRegister(0x00) != 0)
        ;  // waiting for a result
}

void ColorSensor::getOffset() {
    digitalWrite(ledPin, LOW);
    delay(10);

    // Start sensing
    writeRegister(0x02, 0x00);
    while (readRegister(0x00) != 0)
        ;  // waiting for a result
    // writeRegister(0x01, 0x01);  // set trim
    // delay(100);

    for (int i = 0; i < 4; i++)
        colorOffset[i] = (signed char)readRegister(OFFSET_RED + i);

    digitalWrite(ledPin, HIGH);
}

void ColorSensor::writeRegister(unsigned char data, unsigned char address) {
    Wire.beginTransmission(ADJD_S311_ADDRESS);
    Wire.write(address);
    Wire.write(data);
    Wire.endTransmission();
}

unsigned char ColorSensor::readRegister(unsigned char address) {
    unsigned char data;

    Wire.beginTransmission(ADJD_S311_ADDRESS);
    Wire.write(address);
    Wire.endTransmission();

    Wire.requestFrom(ADJD_S311_ADDRESS, 1);
    while (!Wire.available())
        ;  // wait till we can get data

    return Wire.read();
}

int ColorSensor::readRegisterInt(unsigned char address) {
    return readRegister(address) + (readRegister(address + 1) << 8);
}

RGBC ColorSensor::read() {
    // Read data registers and return a RGBC var
    RGBC color = RGBC();

    performMeasurement();

    color.red = readRegisterInt(DATA_RED_LO);
    color.green = readRegisterInt(DATA_GREEN_LO);
    color.blue = readRegisterInt(DATA_BLUE_LO);
    color.clear = readRegisterInt(DATA_CLEAR_LO);

    return color;
}
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

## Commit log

2019-05-06 Classe para controle do robo
2019-05-06 Testes motor com encoder
2019-06-01 Inicial code with interrupt
2019-08-24 Classe do motor com interrupt como método
2019-08-24 Classe sensor criada; Métodos de movimentação adicionados; Primeiros métodos da maquina de estados;
2019-08-31 Configs para arduino uno
2019-08-31 Classe do sensor de distancia
2019-08-31 Classe que encapsula o sensor de distancia
2019-08-31 Teste do sensor de distancia
2019-09-01 Métodos de movimentação funcionais. métodos de garra e elevador integrados.
2019-09-10 Classe do sensor de cor
2019-09-10 Funções de teste e integração com o sensor de cor
2019-09-10 Teste do sensor de cor
2019-09-14 Add button for robot config & color sensor calibr
2019-09-14 PWM reduction
2019-09-15 moving class claw to dir claw
2019-09-17 comandos motor travantes
2019-09-17 coisas que não precisam estar aqui
2019-09-18 Line Sensor class refactoring
2019-09-19 Add shield specification files
    [esquema_placa_v2.brd, esquema_placa_v2.sch]
2019-09-28 removing .vscode from track
2019-10-03 New Claw stuff
2019-10-03 Função para retornar a zona de containers
2019-10-11 alinhar com container com odometria
2019-10-11 Ir para a segunda pilha dos navios
2019-10-13 Novo sensor de cor do nosso lider
2019-10-13 Adaptando ao novo sensor de cor
2019-10-16 ajustes finos para sequencia de tarefas -- alinhar antes de pegar o container
2019-10-18 New color sensor and claw

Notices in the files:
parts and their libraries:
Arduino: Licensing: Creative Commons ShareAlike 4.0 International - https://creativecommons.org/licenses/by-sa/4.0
